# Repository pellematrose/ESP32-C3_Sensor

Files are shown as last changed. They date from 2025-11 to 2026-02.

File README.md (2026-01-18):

# ESP32-C3\_Sensor

Sensor Board to read two PT100 sensors and a Barometer. Show the measurements on a OLED Display and Broadcast over MQTT.  
With li-ion charger over USB-C.

## Hardware Components

* Two channel PT100
* Li-Ion Charging and protection circuit
* Blue user LED
* User button
* 0.9" OLED
* Li-Ion Battery connector
* Barometer

## Software Modules

* Two channel PT100 measurement with calibration.
* Access point to calibrate and configure the device and to get device information like battery voltage and temperatures.
* Measure battery voltage. (if connected)
* Display temperatures and voltage on OLED.
* Barometer
* MQTT
* Deepsleep

Device:

* Use it as stand-alone device to measure up to two temperatures and show on display. No Wifi needed.
* Use it as stand-alone device to measure up to two temperatures and check over access point.
* Use it as headless device to measure up to two temperatures and broadcast over MQTT.
* Combine the modes.
* Use it as a battery device.
* Use it without battery.
* Use it as you want. Write your own code. Use existing code. Modify existing code.
* Use. Modify. Write. Code.

# Info

All open source!

Hardware licensed under CERN-OHL-S v2 

Firmware licensed under MIT License

Makes use of mongoose.wz for HTML UI.

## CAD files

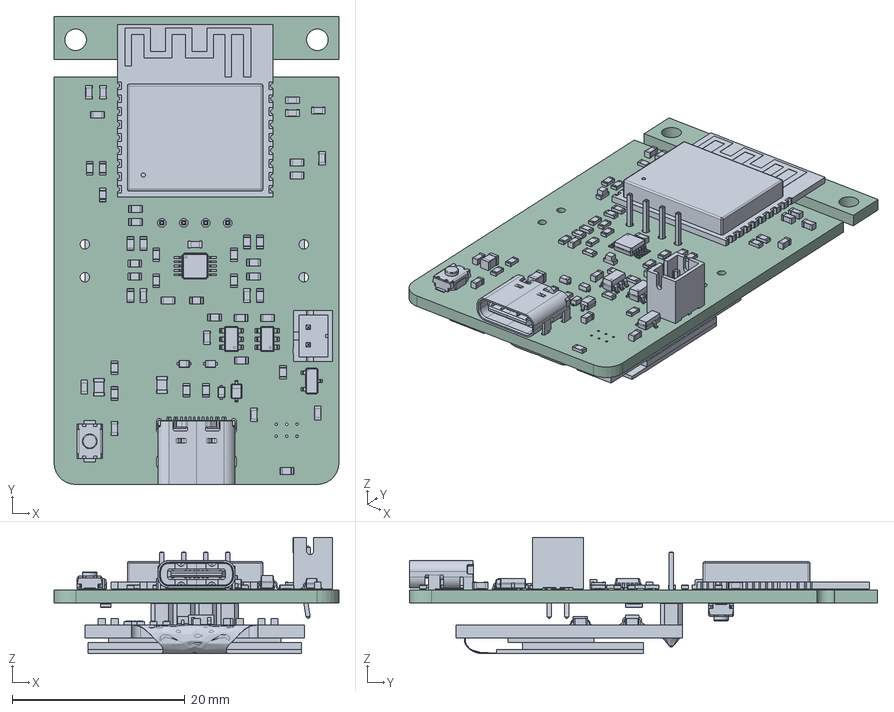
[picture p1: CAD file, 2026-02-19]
Hardware/ESP32-C3_Sensor/production_2026-02-19/step/ESP32-C3_Sensor.step
33.0 x 54.2 x 13.5 mm
R_0603_1608Metric x 32
C_0603_1608Metric x 15
SOT-23-3
JST_PH_B2B-PH-K_1x02_P2.00mm_Vertical
C_0805_2012Metric x 2
TS-1088-AR02016--3DModel-STEP-269445 x 2
ESP32-C3-WROOM-02
D_SOD-323
D_SOD-523 x 3
SOT-23-6 x 2
LED_0603_1608Metric x 2
USB_C_Receptacle_GCT_USB4105-xx-A_16P_TopMnt_Horizontal
VSSOP-10_3x3mm_P0.5mm
R_0805_2012Metric
board
screen
pin_header
soldering
smd_capacitor
smd_capacitor (1)
914_smd_resistor
472_smd_resistor x 3
t4_smd_diode
smd_capacitor (2)
smd_capacitor (3)
smd_capacitor (4)
smd_capacitor (5)
smd_capacitor (6)
472_smd_resistor (1)
SOT-23_XC6206 v3
smd_capacitor (7)
flat_cable
ESP32-C3_Sensor_PCB

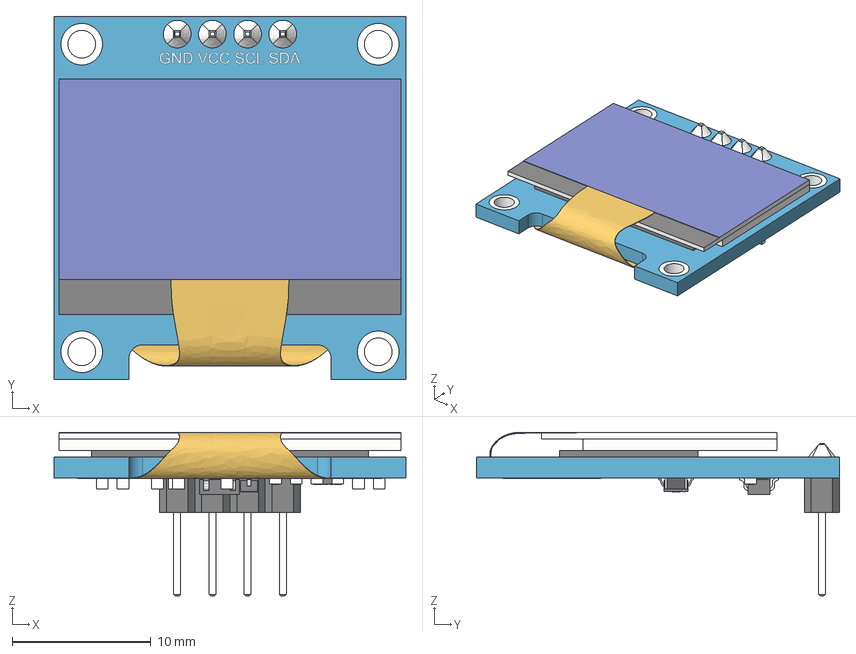
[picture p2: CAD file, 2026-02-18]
Hardware/ESP32-C3_Sensor/source_2026-02-19/3dmodels/SSD1306_OLED_Display(128x64).step
25.4 x 26.2 x 11.8 mm
board
screen
pin_header
soldering
smd_capacitor
smd_capacitor (1)
914_smd_resistor
472_smd_resistor x 3
t4_smd_diode
smd_capacitor (2)
smd_capacitor (3)
smd_capacitor (4)
smd_capacitor (5)
smd_capacitor (6)
472_smd_resistor (1)
SOT-23_XC6206 v3
smd_capacitor (7)
flat_cable

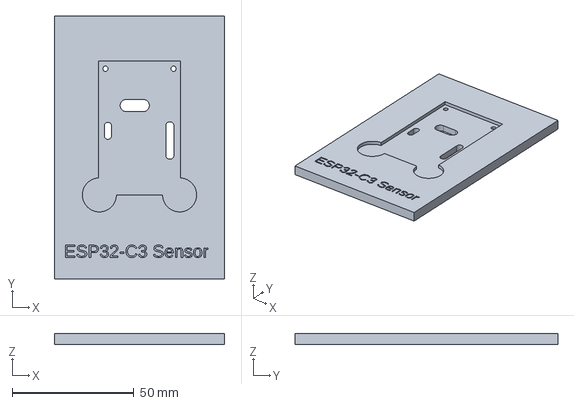
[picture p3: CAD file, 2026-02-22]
Stencil Jig/Stencil Jig.FCStd
70.0 x 108.2 x 4.60 mm

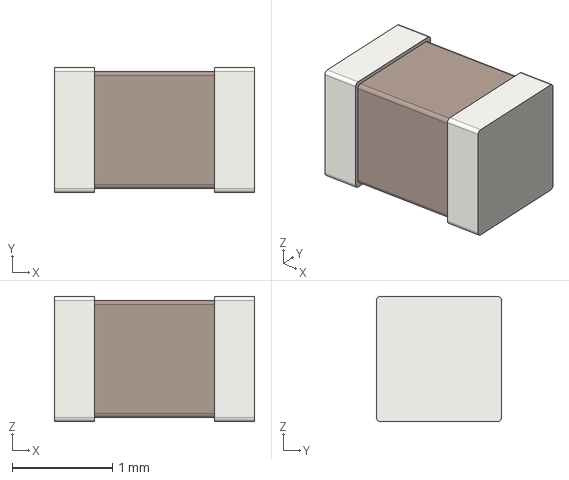
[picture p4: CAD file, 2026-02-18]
Hardware/ESP32-C3_Sensor/source_2026-02-19/3dmodels/C_0805_2012Metric.step
2.00 x 1.25 x 1.25 mm

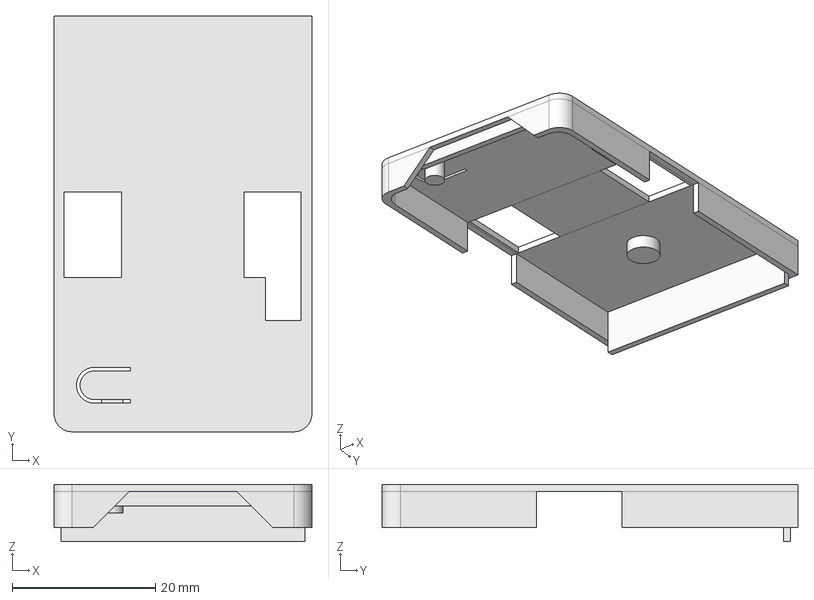
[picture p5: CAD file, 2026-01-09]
Housing/Housing-Top.step
36.0 x 58.0 x 8.00 mm

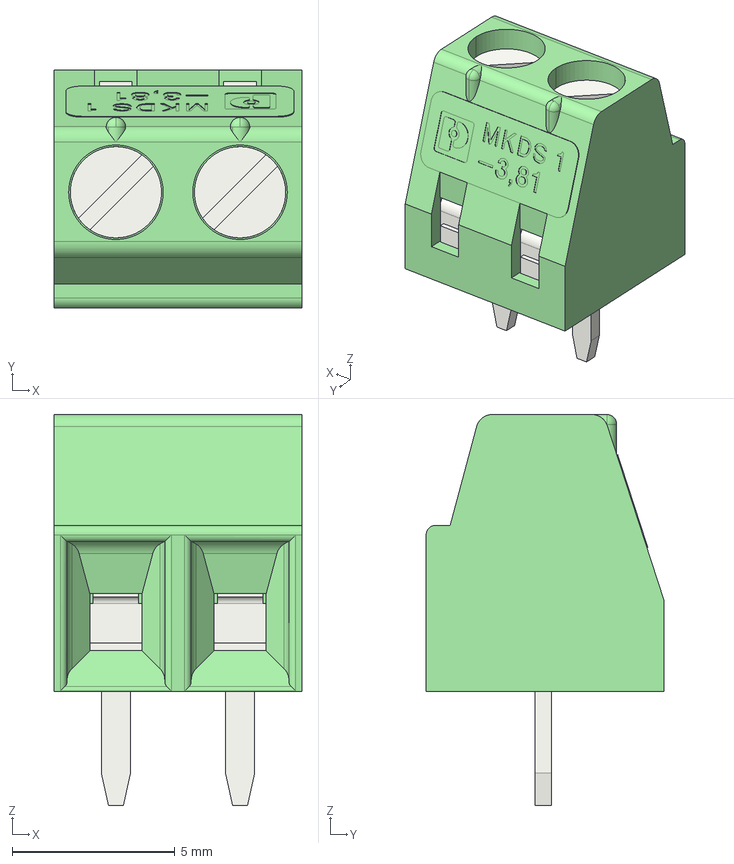
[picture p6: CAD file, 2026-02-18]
Hardware/ESP32-C3_Sensor/source_2026-02-19/3dmodels/TerminalBlock_Phoenix_MKDS-1-2-3.81_1x02_P3.81mm_Horizontal.stp
7.61 x 7.30 x 12.0 mm

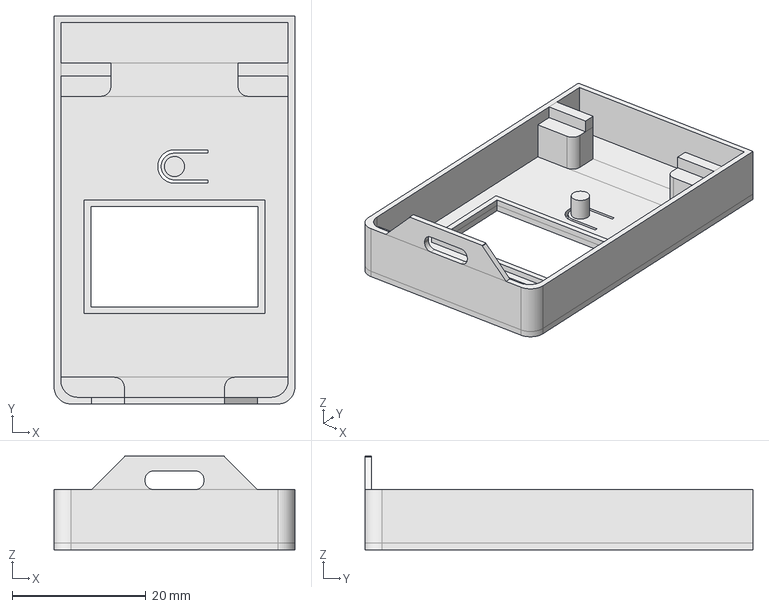
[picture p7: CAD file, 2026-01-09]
Housing/Housing-Bottom.step
36.0 x 58.0 x 14.0 mm

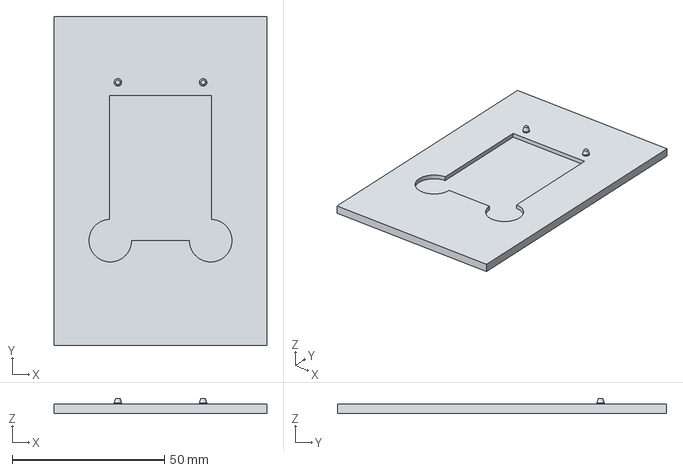
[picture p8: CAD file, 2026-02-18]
Stencil Jig/Stencil Jig-BodyPad002.step
70.0 x 108.2 x 5.00 mm

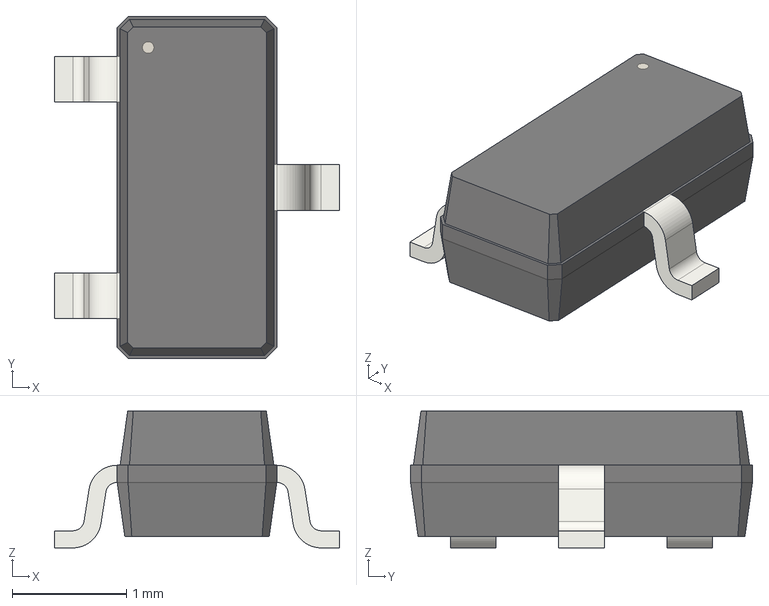
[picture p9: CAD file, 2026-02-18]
Hardware/ESP32-C3_Sensor/source_2026-02-19/3dmodels/SOT-23-3.step
2.50 x 3.00 x 1.20 mm

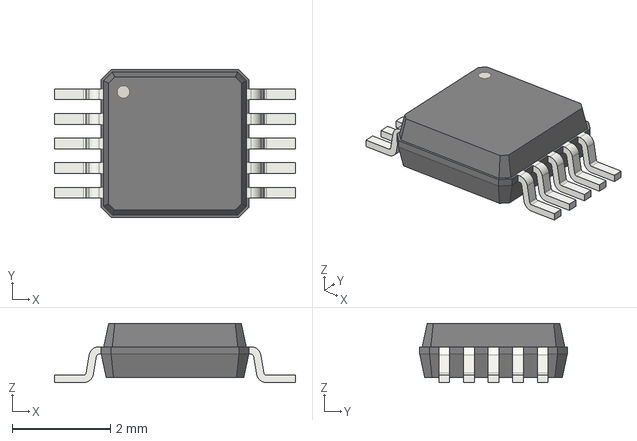
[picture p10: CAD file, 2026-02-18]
Hardware/ESP32-C3_Sensor/source_2026-02-19/3dmodels/VSSOP-10_3x3mm_P0.5mm.step
4.90 x 3.00 x 1.20 mm

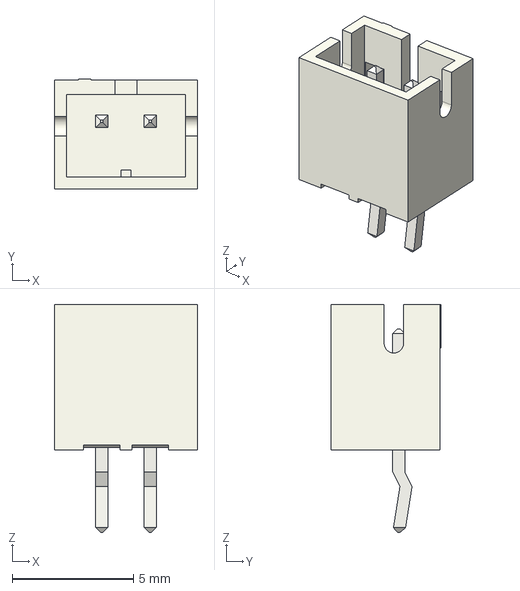
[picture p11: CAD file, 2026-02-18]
Hardware/ESP32-C3_Sensor/source_2026-02-19/3dmodels/JST_PH_B2B-PH-K_1x02_P2.00mm_Vertical.step
5.90 x 4.55 x 9.40 mm

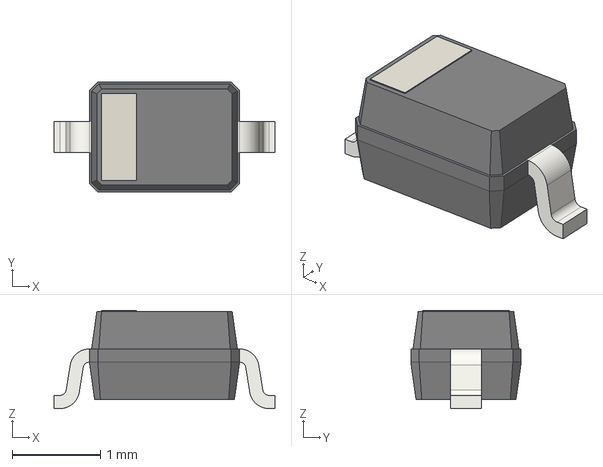
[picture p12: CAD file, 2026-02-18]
Hardware/ESP32-C3_Sensor/source_2026-02-19/3dmodels/D_SOD-323.step
2.50 x 1.25 x 1.11 mm

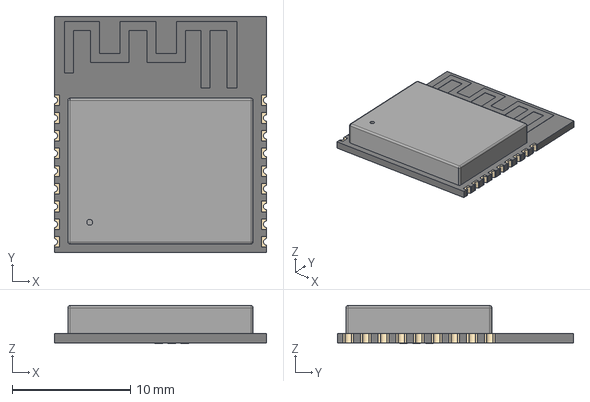
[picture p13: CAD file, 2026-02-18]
Hardware/ESP32-C3_Sensor/source_2026-02-19/3dmodels/ESP32-C3-WROOM-02.step
18.0 x 20.0 x 3.24 mm

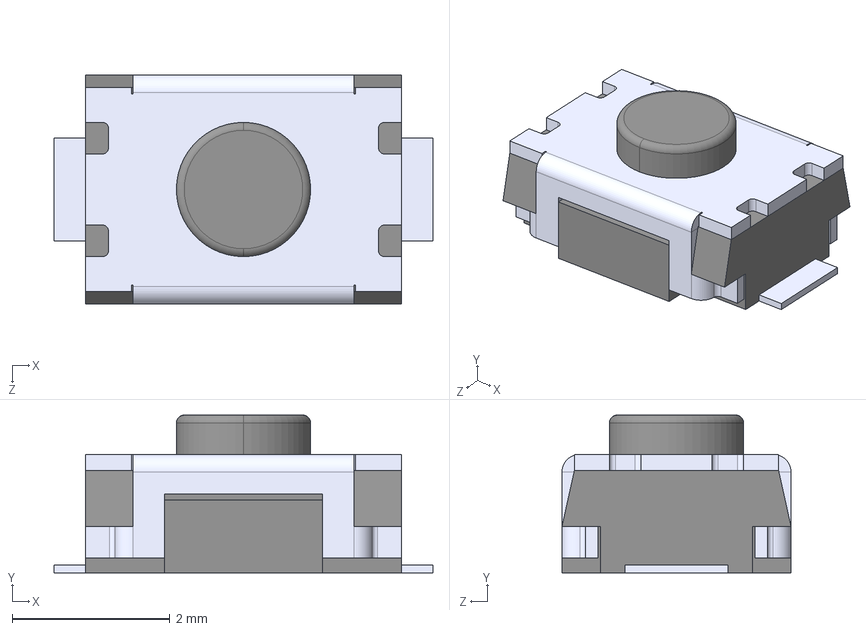
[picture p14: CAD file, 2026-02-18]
Hardware/ESP32-C3_Sensor/source_2026-02-19/3dmodels/TS-1088-AR02016--3DModel-STEP-269445.STEP
4.80 x 2.00 x 2.90 mm

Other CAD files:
Housing/Housing.FCStd
Stencil Jig/Stencil Jig-BodyPocket.step
Hardware/ESP32-C3_Sensor/source_2026-02-19/3dmodels/R_0805_2012Metric.step
Hardware/ESP32-C3_Sensor/source_2026-02-19/3dmodels/D_SOD-523.step
Hardware/ESP32-C3_Sensor/source_2026-02-19/3dmodels/BMP388.step
Hardware/ESP32-C3_Sensor/source_2026-02-19/3dmodels/C_0603_1608Metric.step
Hardware/ESP32-C3_Sensor/source_2026-02-19/3dmodels/LED_0603_1608Metric.step
Hardware/ESP32-C3_Sensor/source_2026-02-19/3dmodels/R_0603_1608Metric.step
Hardware/ESP32-C3_Sensor/source_2026-02-19/3dmodels/SOT-23-6.step
Hardware/ESP32-C3_Sensor/source_2026-02-19/3dmodels/USB_C_Receptacle_GCT_USB4105-xx-A_16P_TopMnt_Horizontal.step
Stencil Jig/20260221_Stencil Jig-BodyPocket001.step

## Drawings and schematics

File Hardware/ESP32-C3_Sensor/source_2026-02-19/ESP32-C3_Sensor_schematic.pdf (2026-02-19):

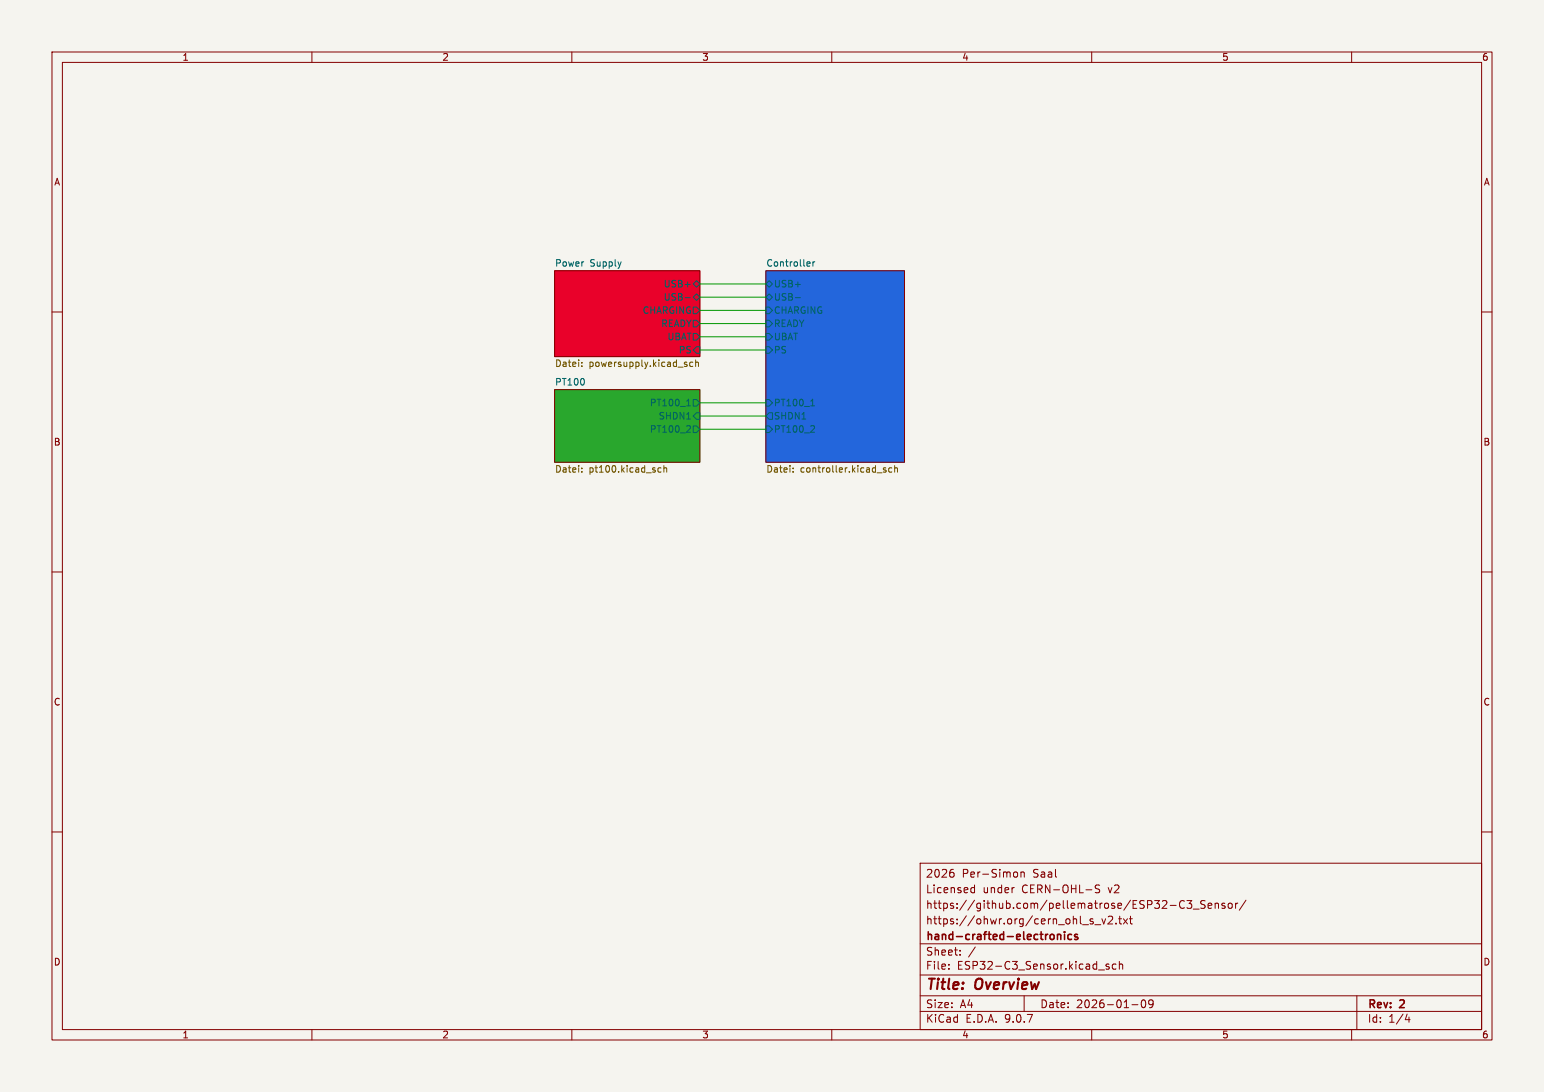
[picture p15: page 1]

UBAT PS Controller Datei: controller.kicad_sch PT100_1 SHDN1 PT100_2 PT100 Datei: pt100.kicad_sch USB+ USB- CHARGING

Power Supply Datei: powersupply.kicad_sch

USB+ USB- SHDN1 PT100_1 PT100_2 READY CHARGING

https://ohwr.org/cern_ohl_s_v2.txt
File: ESP32-C3_Sensor.kicad_sch Sheet: / hand-crafted-electronics

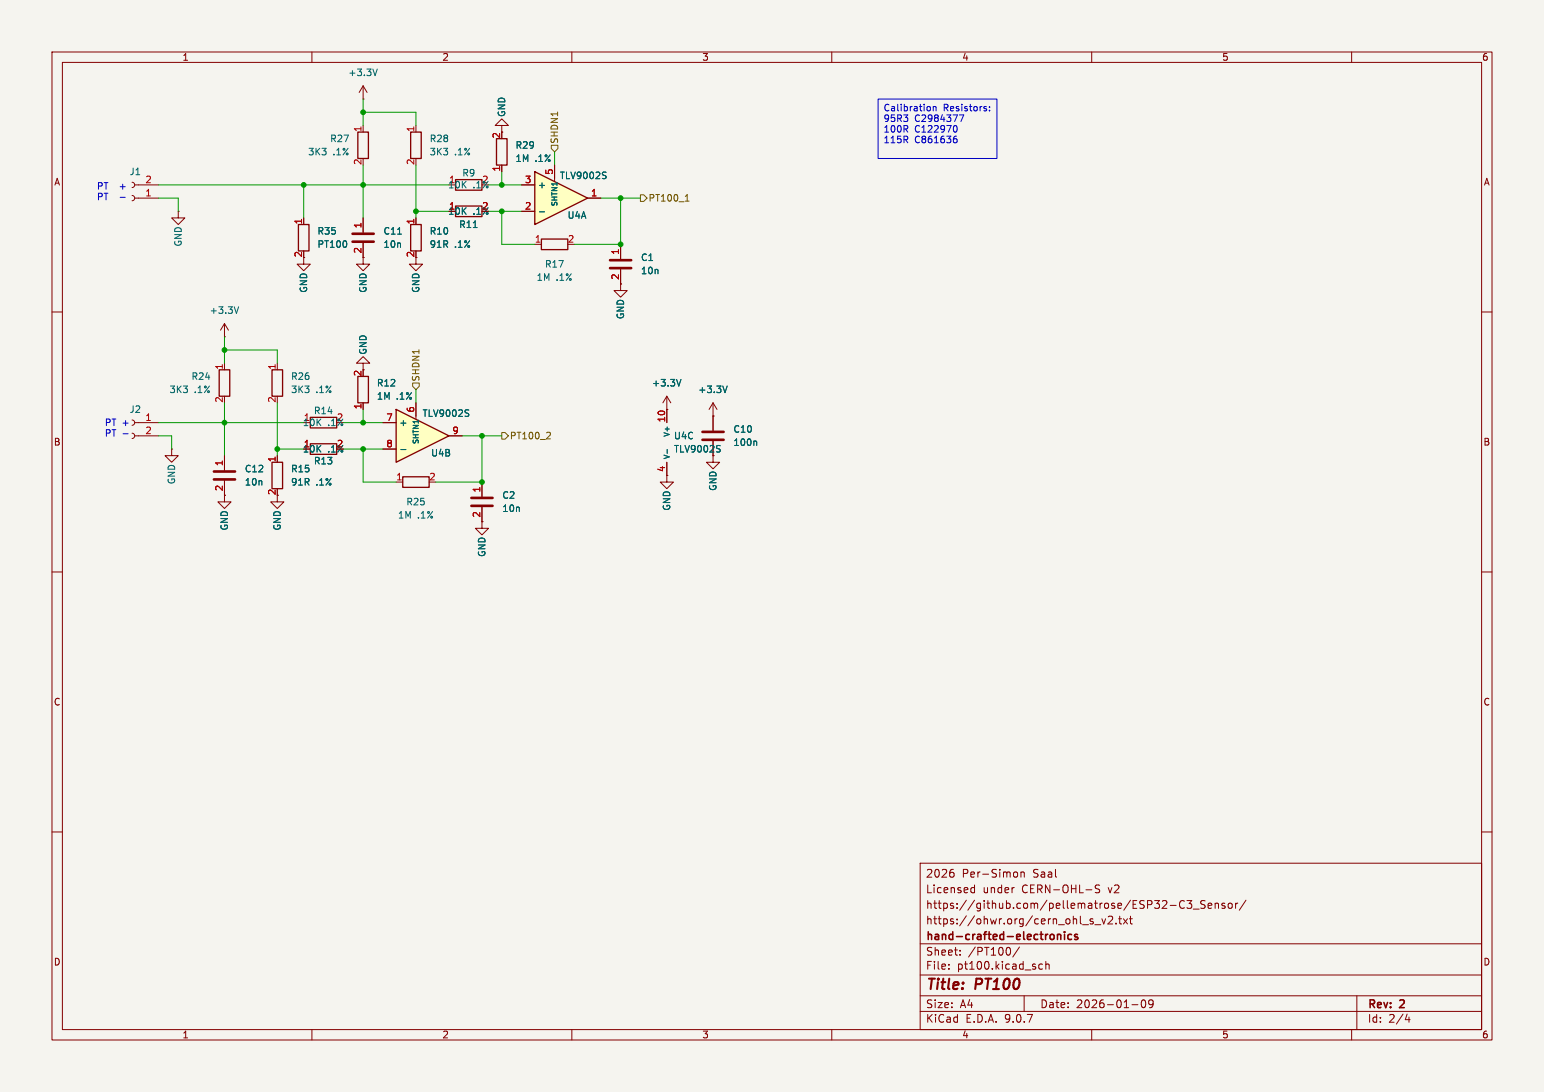
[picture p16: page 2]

https://ohwr.org/cern_ohl_s_v2.txt
File: pt100.kicad_sch Sheet: /PT100/ hand-crafted-electronics

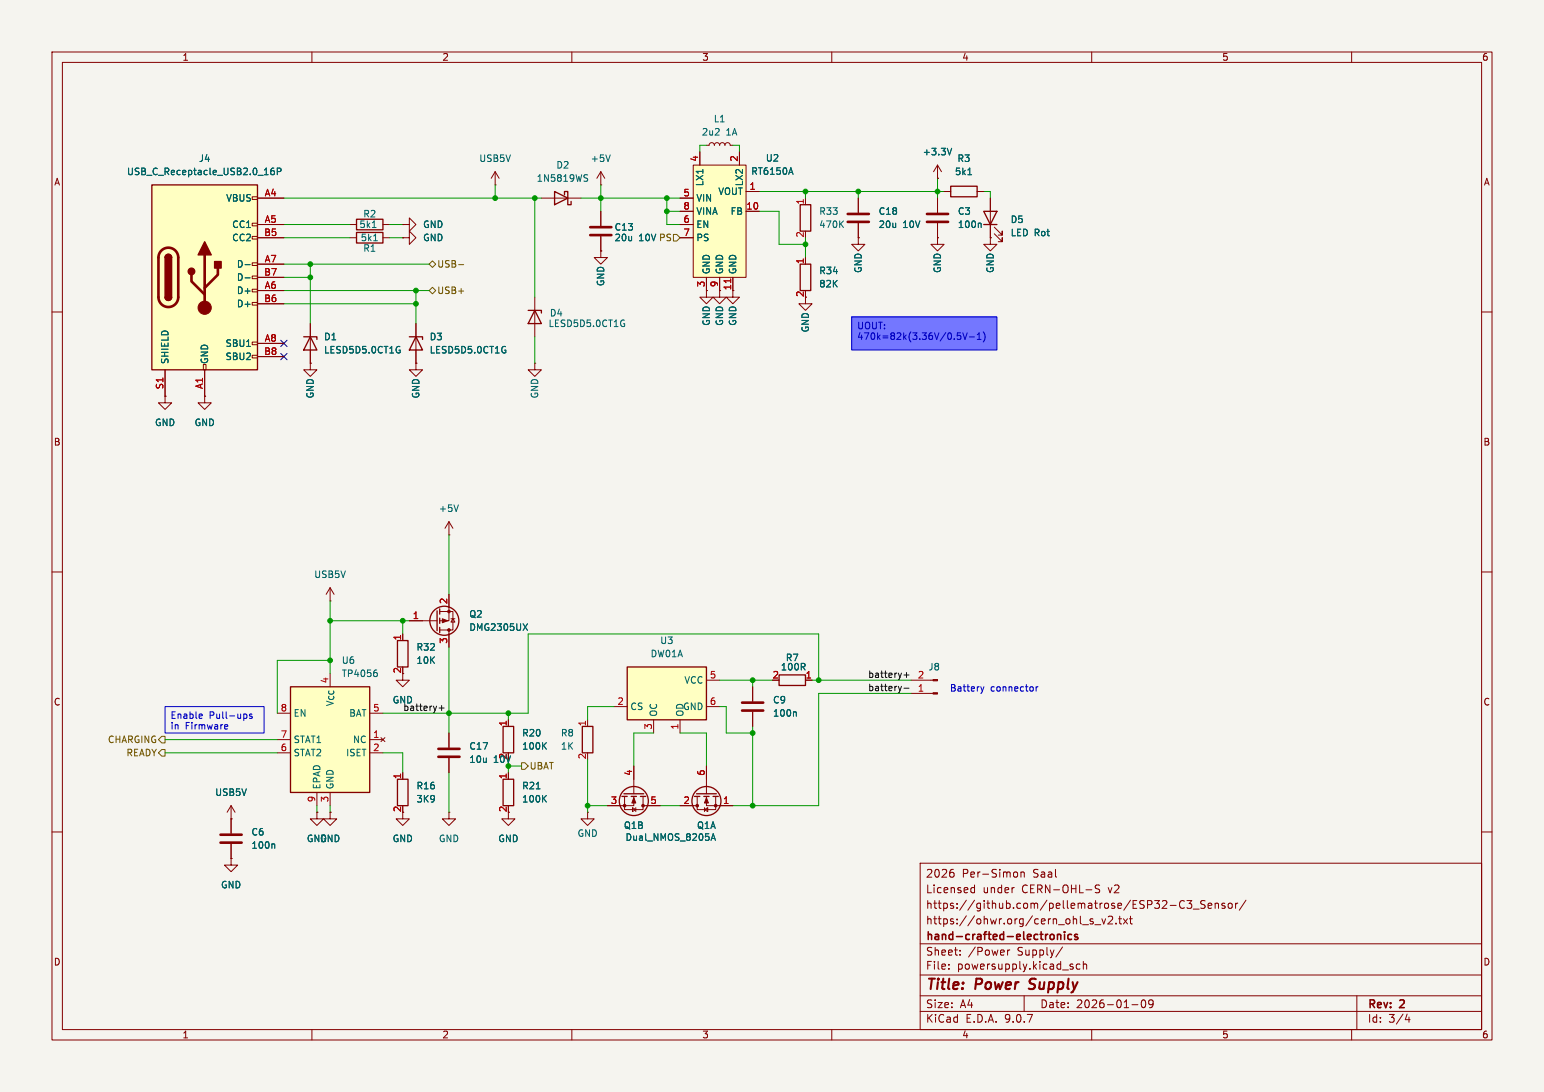
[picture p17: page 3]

VIN 5 VINA 8 EN 6 PS 7 LX1

2 VOUT 1 FB 10 U2 RT6150A

battery+ Enable Pull-ups

https://ohwr.org/cern_ohl_s_v2.txt

Id: 3/4 Title: Power Supply

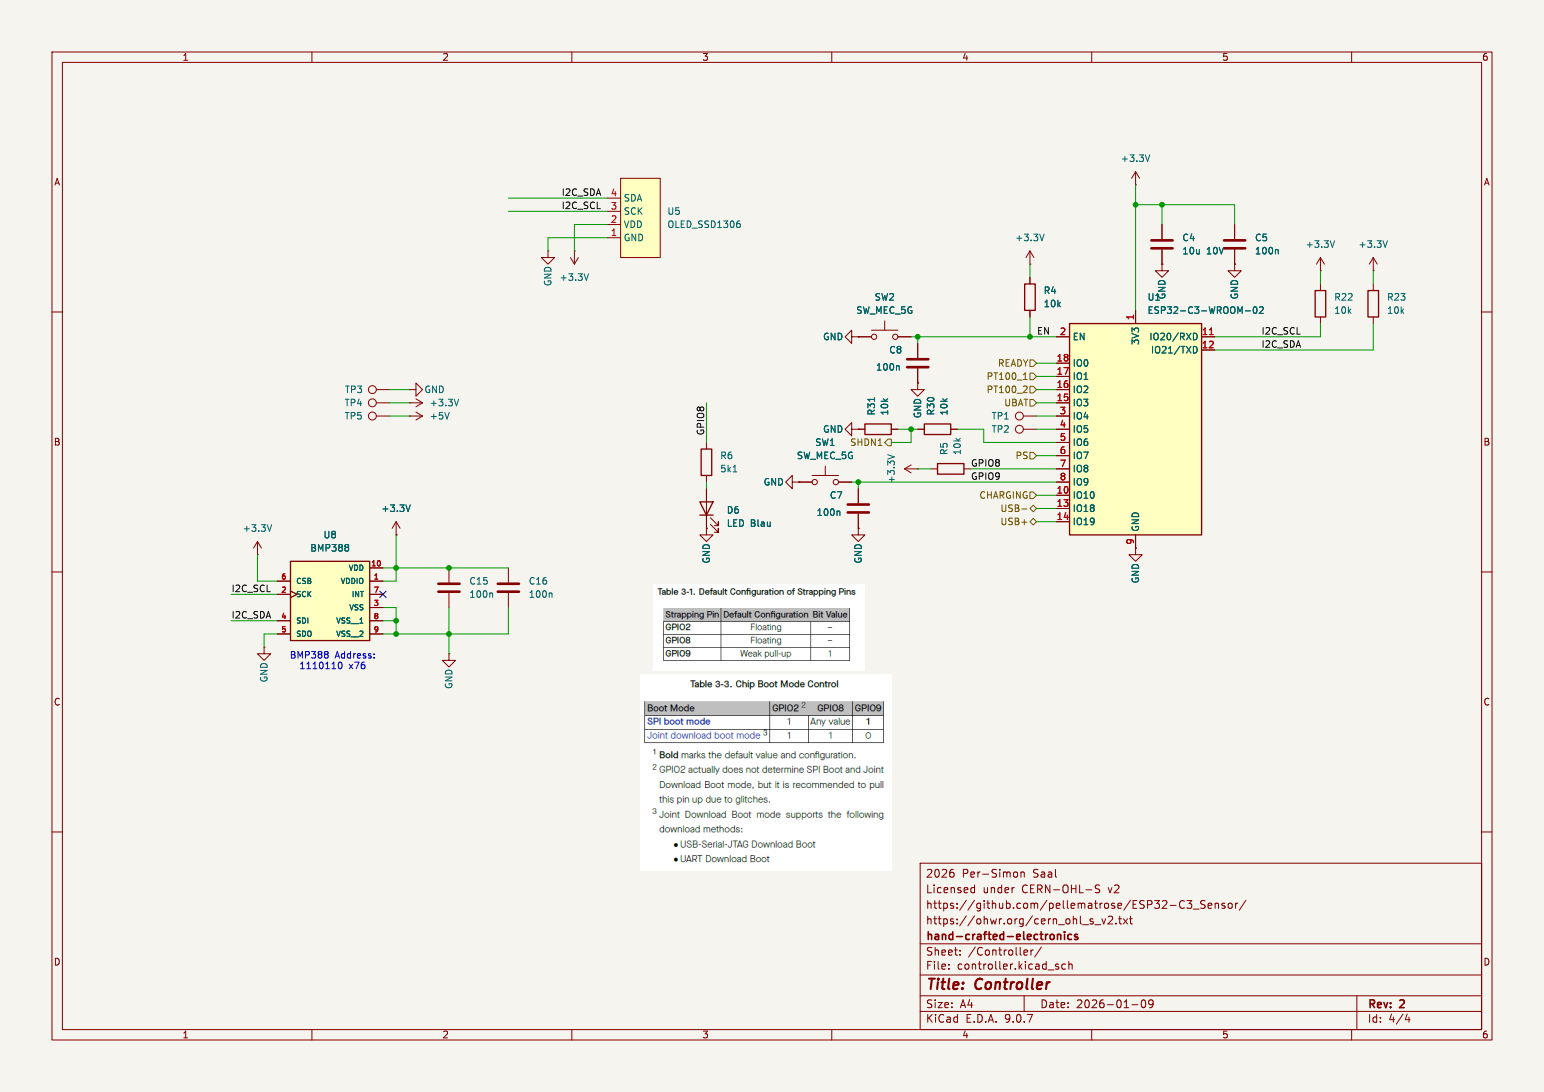
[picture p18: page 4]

https://ohwr.org/cern_ohl_s_v2.txt
Id: 4/4 Title: Controller File: controller.kicad_sch Sheet: /Controller/ hand-crafted-electronics

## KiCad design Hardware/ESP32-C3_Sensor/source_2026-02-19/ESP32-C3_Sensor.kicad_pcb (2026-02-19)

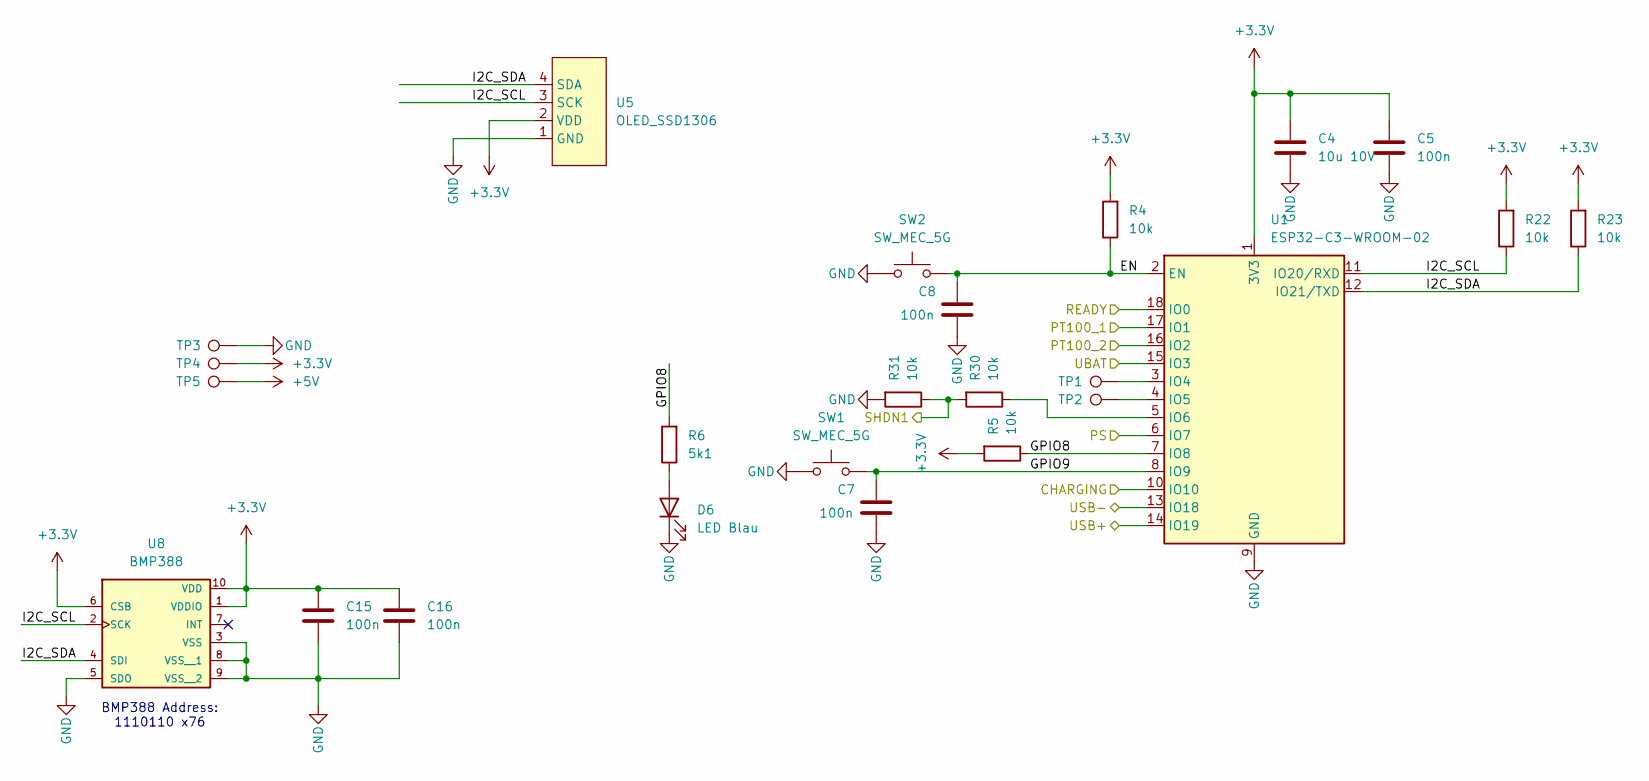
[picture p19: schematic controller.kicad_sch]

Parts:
C4: 10u 10V; C_0603_1608Metric; LCSC C2959727
C5, C7, C8, C15, C16: 100n; C_0603_1608Metric
D6: LED Blau; LED_0603_1608Metric; LCSC C965807
R4, R5, R22, R23, R30, R31: 10k; R_0603_1608Metric; LCSC C25804
R6: 5k1; R_0603_1608Metric; LCSC C431786
SW1, SW2: SW_MEC_5G; Xunpu TS-1088; LCSC C720477
TP1, TP2, TP3, TP4, TP5: TestPoint; TestPoint_Pad_D1.5mm
U1: ESP32-C3-WROOM-02; LCSC C2934560
U5: OLED_SSD1306; SSD1306_0.96_Oled
U8: BMP388; PQFN50P200X200X80-10N; PARTREV 1.1; LCSC C779278

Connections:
+3.3V: C4.1, C5.1, C15.1, C16.1, R4.2, R5.2, R22.2, R23.2, TP4.1, U1.1 (3V3), U5.2 (VDD), U8.1 (VDDIO), U8.6 (CSB), U8.10 (VDD); also elsewhere on the board
+5V: TP5.1; also elsewhere on the board
/Controller/CHARGING: U1.10 (IO10); also elsewhere on the board
/Controller/EN: C8.1, R4.1, SW2.2 (B), U1.2 (EN)
/Controller/GPIO8: R5.1, R6.2, U1.7 (IO8)
/Controller/GPIO9: C7.1, SW1.2 (B), U1.8 (IO9)
/Controller/I2C_SCL: R22.1, U1.11 (IO20/RXD), U5.3 (SCK), U8.2 (SCK)
/Controller/I2C_SDA: R23.1, U1.12 (IO21/TXD), U5.4 (SDA), U8.4 (SDI)
/Controller/PS: U1.6 (IO7); also elsewhere on the board
/Controller/PT100_1: U1.17 (IO1); also elsewhere on the board
/Controller/PT100_2: U1.16 (IO2); also elsewhere on the board
/Controller/READY: U1.18 (IO0); also elsewhere on the board
/Controller/SHDN1: R30.2, R31.1; also elsewhere on the board
/Controller/UBAT: U1.15 (IO3); also elsewhere on the board
/Controller/USB+: U1.14 (IO19); also elsewhere on the board
/Controller/USB-: U1.13 (IO18); also elsewhere on the board
GND: C4.2, C5.2, C7.2, C8.2, C15.2, C16.2, D6.1 (K), R31.2, SW1.1 (A), SW2.1 (A), TP3.1, U1.9 (GND), U1.19 (GND), U5.1 (GND), U8.3 (VSS), U8.5 (SDO), U8.8 (VSS__1), U8.9 (VSS__2); also elsewhere on the board
unnamed: D6.2 (A), R6.1
unnamed: TP1.1, U1.3 (IO4)
unnamed: TP2.1, U1.4 (IO5)
unnamed: R30.1, U1.5 (IO6)

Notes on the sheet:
BMP388 Address: 1110110 x76

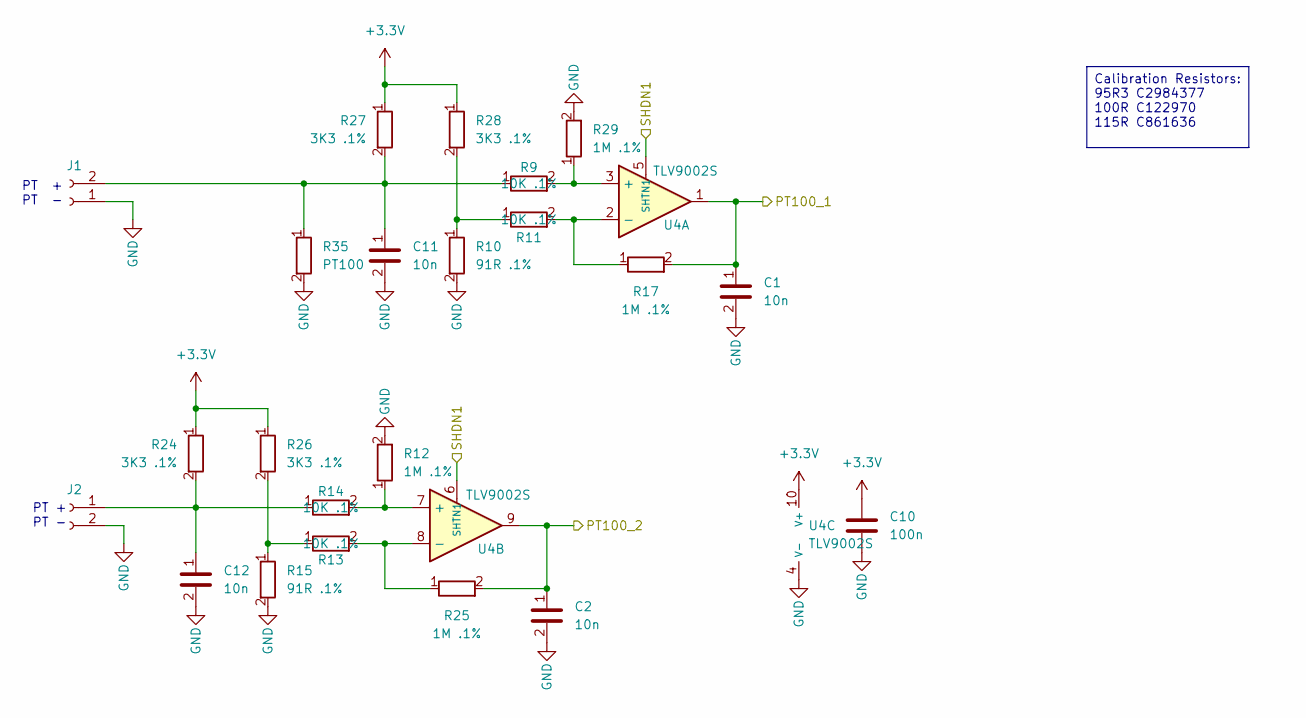
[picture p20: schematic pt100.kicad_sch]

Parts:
C1, C2, C11, C12: 10n; C_0603_1608Metric
C10: 100n; C_0603_1608Metric
J1, J2: Conn_01x02_Socket; TerminalBlock_Phoenix_MKDS-1-2-3.81_1x02_P3.81mm_Horizontal
R9, R11, R13, R14: 10K .1%; R_0603_1608Metric; LCSC C95204
R10, R15: 91R .1%; R_0603_1608Metric; LCSC C862316
R12, R17, R25, R29: 1M .1%; R_0603_1608Metric; LCSC C2989464
R24, R26, R27, R28: 3K3 .1%; R_0603_1608Metric; LCSC C309653
R35: PT100; R_0805_2012Metric
U4: TLV9002S; VSSOP-10_3x3mm_P0.5mm; LCSC C2058239

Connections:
+3.3V: C10.1, R24.1, R26.1, R27.1, R28.1, U4.10 (V+); also elsewhere on the board
/Controller/PT100_1: C1.1, R17.2, U4.1; also elsewhere on the board
/Controller/PT100_2: C2.1, R25.2, U4.9; also elsewhere on the board
/Controller/SHDN1: U4.5 (SHTN1), U4.6 (SHTN1); also elsewhere on the board
GND: C1.2, C2.2, C10.2, C11.2, C12.2, J1.1, J2.2, R10.2, R12.2, R15.2, R29.2, R35.2, U4.4 (V-); also elsewhere on the board
unnamed: C11.1, J1.2, R9.1, R27.2, R35.1
unnamed: C12.1, J2.1, R14.1, R24.2
unnamed: R10.1, R11.1, R28.2
unnamed: R13.1, R15.1, R26.2
unnamed: R9.2, R29.1, U4.3 (+)
unnamed: R11.2, R17.1, U4.2 (-)
unnamed: R12.1, R14.2, U4.7 (+)
unnamed: R13.2, R25.1, U4.8 (-)

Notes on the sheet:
PT + PT -
PT + PT -
Calibration Resistors: 95R3 C2984377 100R C122970 115R C861636

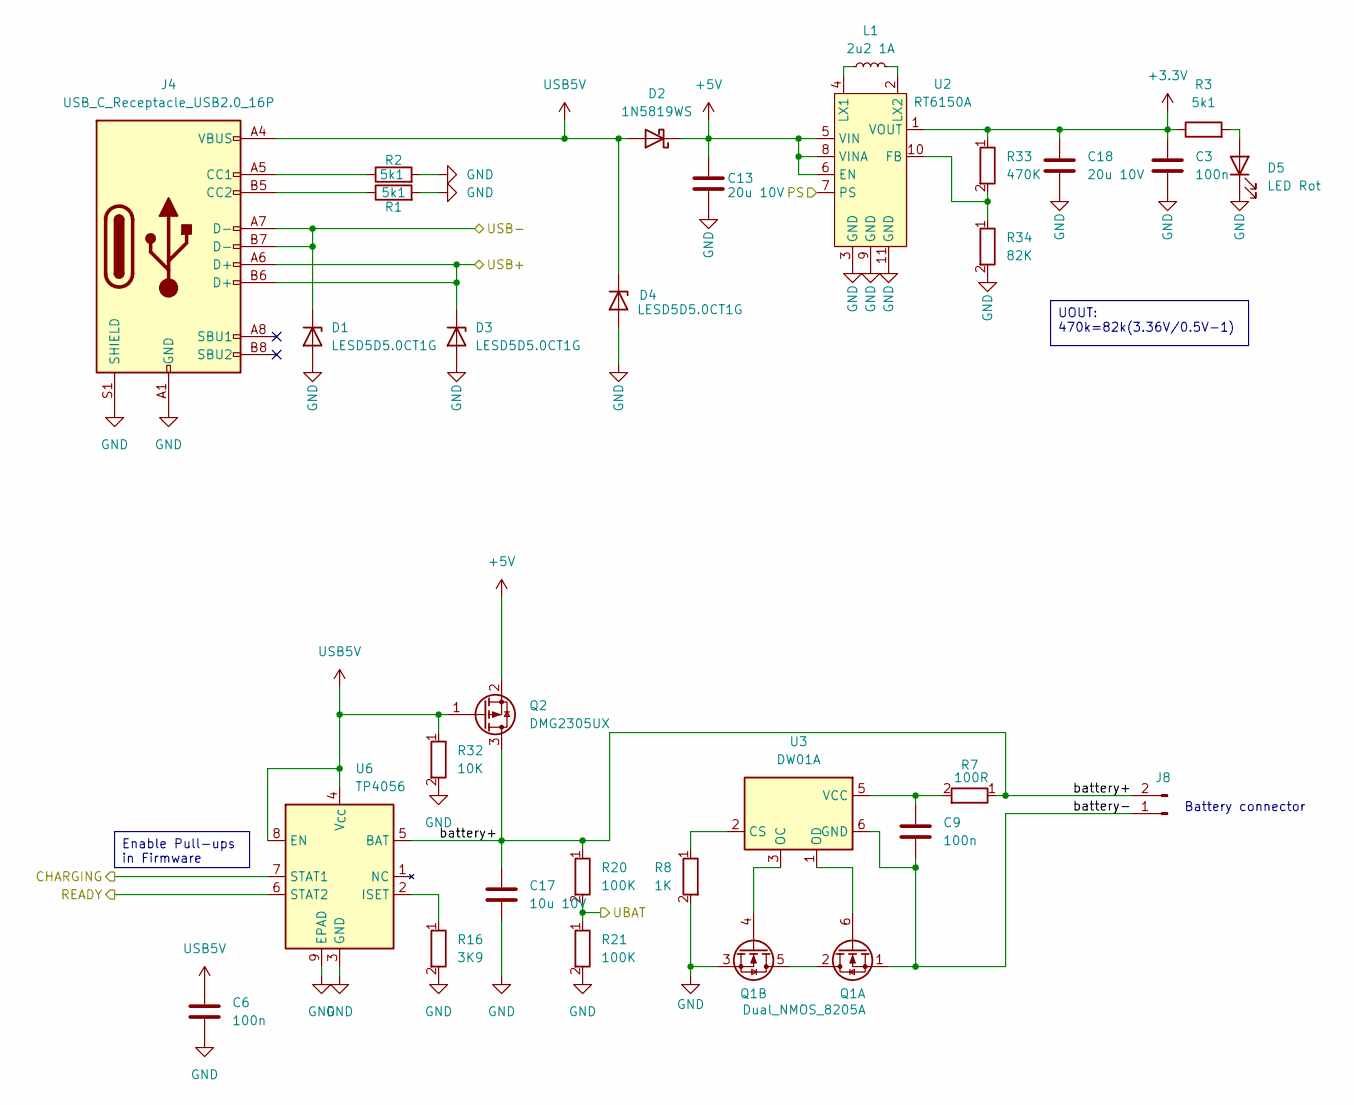
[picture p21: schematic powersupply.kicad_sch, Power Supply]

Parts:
C3, C6, C9: 100n; C_0603_1608Metric
C13, C18: 20u 10V; C_0805_2012Metric
C17: 10u 10V; C_0603_1608Metric; LCSC C2959727
D1, D3, D4: LESD5D5.0CT1G; D_SOD-523; LCSC C383211
D2: 1N5819WS; D_SOD-323; LCSC C2939001
D5: LED Rot; LED_0603_1608Metric; LCSC C965799
J4: USB_C_Receptacle_USB2.0_16P; USB_C_Receptacle_GCT_USB4105-xx-A_16P_TopMnt_Horizontal; LCSC C2988369
J8: Conn_01x02_Pin; JST_PH_B2B-PH-K_1x02_P2.00mm_Vertical
L1: 2u2 1A; Inductor_1210; LCSC C39846664
Q1: Dual_NMOS_8205A; SOT-23-6; LCSC C5370944
Q2: DMG2305UX; SOT-23-3; LCSC C150470
R1, R2, R3: 5k1; R_0603_1608Metric; LCSC C431786
R7: 100R; R_0603_1608Metric; LCSC C22775
R8: 1K; R_0603_1608Metric; LCSC C21190
R16: 3K9; R_0603_1608Metric; LCSC C23018
R20, R21: 100K; R_0603_1608Metric; LCSC C25803
R32: 10K; R_0603_1608Metric; LCSC C25804
R33: 470K; R_0603_1608Metric; LCSC C23178
R34: 82K; R_0603_1608Metric; LCSC C23254
U2: RT6150A; WDFN-10-1EP_3x3mm_P0.5mm_EP1.8x2.5mm; LCSC C147971
U3: DW01A; SOT-23-6; LCSC C2927799
U6: TP4056; SOIC-8-1EP_3.9x4.9mm_P1.27mm_EP2.41x3.3mm_ThermalVias; LCSC C725790

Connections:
+3.3V: C3.1, C18.1, R3.1, R33.1, U2.1 (VOUT); also elsewhere on the board
+5V: C13.1, D2.1 (K), Q2.2 (S), U2.5 (VIN), U2.6 (EN), U2.8 (VINA); also elsewhere on the board
/Controller/CHARGING: U6.7 (STAT1); also elsewhere on the board
/Controller/PS: U2.7 (PS); also elsewhere on the board
/Controller/READY: U6.6 (STAT2); also elsewhere on the board
/Controller/UBAT: R20.2, R21.1; also elsewhere on the board
/Controller/USB+: D3.1 (K), J4.A6 (D+), J4.B6 (D+); also elsewhere on the board
/Controller/USB-: D1.1 (K), J4.A7 (D-), J4.B7 (D-); also elsewhere on the board
/Power Supply/battery+: C17.1, J8.2, Q2.3 (D), R7.1, R20.1, U6.5 (BAT)
/Power Supply/battery-: C9.2, J8.1, Q1.1 (S), U3.6 (GND)
GND: C3.2, C6.2, C13.2, C17.2, C18.2, D1.2 (A), D3.2 (A), D4.2 (A), D5.1 (K), J4.A1 (GND), J4.A12 (GND), J4.B1 (GND), J4.B12 (GND), J4.S1 (SHIELD), Q1.3 (S), R1.2, R2.2, R8.2, R16.2, R21.2, R32.2, R34.2, U2.3 (GND), U2.9 (GND), U2.11 (GND), U6.3 (GND), U6.9 (EPAD); also elsewhere on the board
unnamed: D5.2 (A), R3.2
unnamed: J4.A5 (CC1), R2.1
unnamed: J4.B5 (CC2), R1.1
unnamed: Q1.2 (D), Q1.5 (D)
unnamed: Q1.6 (G), U3.1 (OD)
unnamed: Q1.4 (G), U3.3 (OC)
unnamed: R33.2, R34.1, U2.10 (FB)
unnamed: L1.1, U2.4 (LX1)
unnamed: L1.2, U2.2 (LX2)
unnamed: R8.1, U3.2 (CS)
unnamed: C9.1, R7.2, U3.5 (VCC)
unnamed: R16.1, U6.2 (ISET)
USB5V: C6.1, D2.2 (A), D4.1 (K), J4.A4 (VBUS), J4.A9 (VBUS), J4.B4 (VBUS), J4.B9 (VBUS), Q2.1 (G), R32.1, U6.4 (V_{CC}), U6.8 (EN)

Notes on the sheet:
Battery connector
UOUT: 470k=82k(3.36V/0.5V-1)
Enable Pull-ups in Firmware

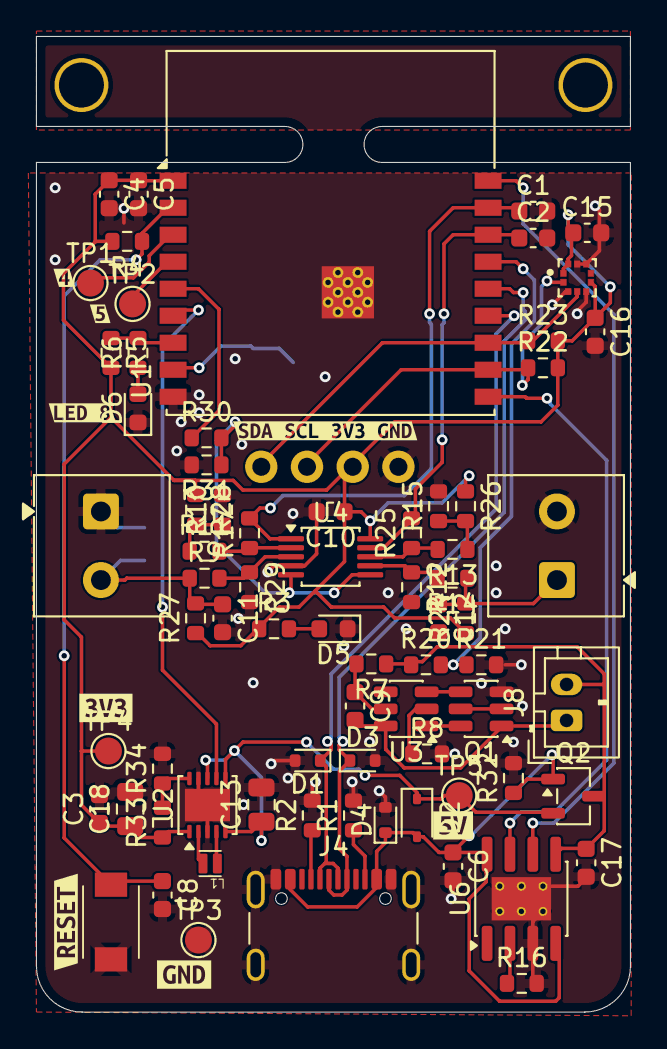
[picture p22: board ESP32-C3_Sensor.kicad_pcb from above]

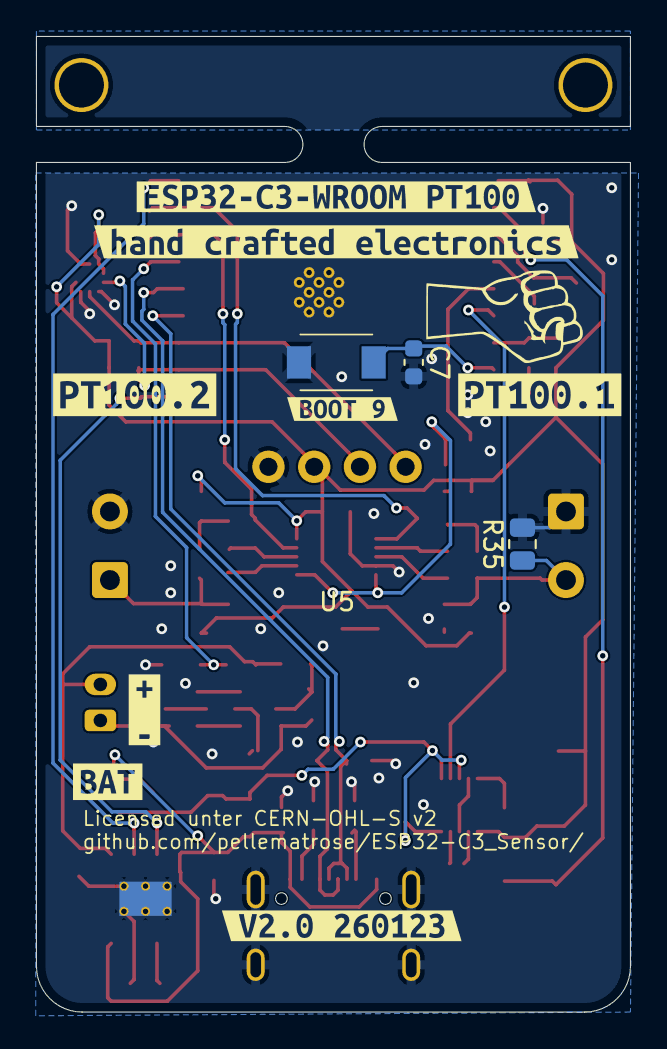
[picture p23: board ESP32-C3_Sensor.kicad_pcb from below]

Board: 2 copper layers, 33.0 x 54.2 mm, 95 parts (12 on the bottom side), 44 nets.

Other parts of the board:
H*: Stencil hole
H*#2: Stencil hole
kibuzzard-68E97F46: G***; kibuzzard-68E97F46
kibuzzard-68E980D7: G***; kibuzzard-68E980D7
kibuzzard-68E983D3: G***; kibuzzard-68E983D3
kibuzzard-68E983DB: G***; kibuzzard-68E983DB
kibuzzard-68E985AE: G***; kibuzzard-68E985AE
kibuzzard-68E986EB: G***; kibuzzard-68E986EB
kibuzzard-68E9848D: G***; kibuzzard-68E9848D
kibuzzard-68E9870E: G***; kibuzzard-68E9870E
kibuzzard-68E98065: G***; kibuzzard-68E98065
kibuzzard-68EE716B: G***; kibuzzard-68EE716B
kibuzzard-68EE7166: G***; kibuzzard-68EE7166
kibuzzard-679A5C2F: G***; kibuzzard-679A5C2F
kibuzzard-679A571E: G***; kibuzzard-679A571E
kibuzzard-696E7314: G***; kibuzzard-696E7314
kibuzzard-69307756: G***; kibuzzard-69307756
kibuzzard-69738792: G***; kibuzzard-69738792

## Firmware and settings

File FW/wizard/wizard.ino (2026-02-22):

/*
 * SPDX-License-Identifier: MIT
 *
 * Copyright (c) 2026 Per-Simon Saal
 */
 
#include "src/mongoose_glue.h"
#include "my_globals.h"

//#include <ESPAsyncWebServer.h>
//#include <AsyncTCP.h>
#include <EEPROM.h>
#include <stdbool.h>
#include "my_functions.h"
#include "setup_pins.h"
#include <driver/adc.h>
#include <esp_adc_cal.h>
#include "temp_func.h"
#include "wifi_manager.h"
#include <U8g2lib.h>
#include "oled_gui.h"
#include <Wire.h>
#include <Adafruit_Sensor.h>
#include "Adafruit_BMP3XX.h"
#include "WiFi.h"
#include "io_func.h"
#include "storage.h"

#define ADC_CHANNEL1 ADC1_CHANNEL_1  // GPIO1
#define ADC_CHANNEL2 ADC1_CHANNEL_2  // GPIO2
#define ADC_CHANNEL3 ADC1_CHANNEL_3  // GPIO3
#define DEFAULT_VREF 1100           // in mV, typischer Wert

// ADC
esp_adc_cal_characteristics_t adc_chars;

// I2C
TwoWire myWire = TwoWire(0);

// OLED
U8G2_SSD1306_128X64_NONAME_F_HW_I2C u8g2(U8G2_R0, /* reset=*/ U8X8_PIN_NONE, /* clock=*/ 20, /* data=*/ 21);   // ESP32 Thing, HW I2C with pin remapping

// BMP388
Adafruit_BMP3XX bmp;

// variables
float temp1 = 0;
float temp2 = 0;
float pressure = 0;
uint32_t vol = 0;
bool chrg = 0;
bool rdy = 0;
float temp1_15min[15];
float temp2_15min[15];
float pressure_15min[15];
float temp1_15minavg = 0;
float temp2_15minavg = 0;
float pressure_15minavg = 0;
uint8_t count = 0;
uint8_t oled_state = 0; // 2: off, 0: temps, 1: bat

// - timing
uint32_t now = 0;
uint32_t last1min = 0;
uint32_t last15min = 0;
uint32_t delta1min = 60000;  
uint32_t delta15min = 900000;
uint32_t oledoff = 5000;
uint32_t olednow = 0;

void setup() {
  Serial.begin(115200);
  delay(100);

  // pin definitions
  setup_pins();
  
  // Legacy ADC konfigurieren
  adc1_config_width(ADC_WIDTH_BIT_12);
  adc1_config_channel_atten(ADC_CHANNEL1, ADC_ATTEN_DB_11); // PT100 1: 0 dB = 0,85V, 2.5dB = 1,3V, 6dB = 2V, 11dB = 3,3V
  adc1_config_channel_atten(ADC_CHANNEL2, ADC_ATTEN_DB_11); // PT100 2
  adc1_config_channel_atten(ADC_CHANNEL3, ADC_ATTEN_DB_11); // Battery voltage
  // Kalibrierung initialisieren
  esp_adc_cal_characterize(ADC_UNIT_1, ADC_ATTEN_DB_11, ADC_WIDTH_BIT_12, DEFAULT_VREF, &adc_chars);

  EEPROM.begin(512); // oder eine andere Größe, je nach Bedarf
  check_magic();
  load(CAL_ADDRESS, (void *)voltages_cal, sizeof(voltages_cal));
  load(ZERO_ADDRESS, (void *)zero_cal, sizeof(zero_cal));

  myWire.begin(21, 20, 400000); // SDA, SCL, Freq
  if(!bmp.begin_I2C(0x76, &myWire)){
    Serial.println("BMP Error.");
  }
  // OLED
  u8g2.begin();
  u8g2.enableUTF8Print();

  // Set up oversampling and filter initialization
  bmp.setTemperatureOversampling(BMP3_OVERSAMPLING_8X);
  bmp.setPressureOversampling(BMP3_OVERSAMPLING_4X);
  bmp.setIIRFilterCoeff(BMP3_IIR_FILTER_COEFF_3);
  bmp.setOutputDataRate(BMP3_ODR_50_HZ);

  // Set logging function to serial print
  mg_log_set_fn([](char ch, void *) { Serial.print(ch); }, NULL);
  mg_log_set(MG_LL_DEBUG);

  connect_wifi();
  mqtt_setup();
  
  // fill arrays with real values
  // TODO: put in own function
  if (! bmp.performReading()) {
  Serial.println("Failed to perform reading :(");
  return;
  }
  for(int i=0; i<15; i++){
    temp1_15min[i] = get_temperature(1) - zero_cal[0];
    temp2_15min[i] = get_temperature(2) - zero_cal[1]+1.7; //TODO: Channel two somehow shows a false value on my hardware (remove 1.7!)
    pressure_15min[i] = bmp.pressure / 100;
  }
  temp1_15minavg = moving_average(temp1_15min, 15);
  temp2_15minavg = moving_average(temp2_15min, 15);
  pressure_15minavg = moving_average(pressure_15min, 15);
  vol = get_voltage(3) * 2; // 100k : 100k voltage divider
  chrg = get_charge_Pin();
  rdy = get_ready_Pin();
  Serial.printf("t1: %.1f, t2: %.1f, p: %.2f, vol: %.3f", temp1_15minavg, temp2_15minavg, pressure_15minavg, vol);
  oled_data(temp1_15minavg, temp2_15minavg, pressure_15minavg);
  // fill array function end

  //esp_sleep_enable_timer_wakeup(900000000);

  mongoose_init();
  mongoose_set_http_handlers("battery", my_get_battery, my_set_battery);
  mongoose_set_http_handlers("temperature", my_get_temperature, my_set_temperature);
  mongoose_set_http_handlers("wifi", my_get_wifi, my_set_wifi);
  mongoose_set_http_handlers("debug", my_get_debug, my_set_debug);
  mongoose_set_http_handlers("mqtt", my_get_mqtt, my_set_mqtt);
  mongoose_set_http_handlers("calibration", my_get_calibration, my_set_calibration);
  mongoose_set_http_handlers("btnhigh", my_check_btnhigh, my_start_btnhigh);
  mongoose_set_http_handlers("btnlow", my_check_btnlow, my_start_btnlow);
  mongoose_set_http_handlers("btnhigh2", my_check_btnhigh2, my_start_btnhigh2);
  mongoose_set_http_handlers("btnlow2", my_check_btnlow2, my_start_btnlow2);
  mongoose_set_http_handlers("resetcal1", my_check_resetcal1, my_start_resetcal1);
  mongoose_set_http_handlers("resetcal2", my_check_resetcal2, my_start_resetcal2);
  mongoose_set_http_handlers("tempoffset1", my_check_tempoffset1, my_start_tempoffset1);
  mongoose_set_http_handlers("tempoffset2", my_check_tempoffset2, my_start_tempoffset2);
  mongoose_set_http_handlers("reboot", my_check_reboot, my_start_reboot);

}

void loop() {
  mongoose_poll();

  now = millis();
  //Serial.println("läuft");
  
  // mqtt
  if(apmode == 1 && mqttdata.en == true){
    mqtt_loop();
  }
  
  
  // time loop one
  if(now - last1min > delta1min){
    last1min = now;

    temp1 = get_temperature(1) - zero_cal[0];
    temp2 = get_temperature(2) - zero_cal[1]+1.7; //TODO: Channel two somehow shows a false value on my hardware (remove 1.7!)
    
    if (! bmp.performReading()) {
      Serial.println("Failed to perform reading :(");
      return;
    }
    pressure = bmp.pressure / 100;
    
    if(count == 15) count = 0; // reset counter when at end of array
    temp1_15min[count] = temp1;
    temp2_15min[count] = temp2;
    pressure_15min[count] = pressure;
    count++;
    temp1_15minavg = moving_average(temp1_15min, 15);
    temp2_15minavg = moving_average(temp2_15min, 15);
    pressure_15minavg = moving_average(pressure_15min, 15);
    //TODO: read battery voltage and charge status
    vol = get_voltage(3) * 2; // 100k : 100k voltage divider
    chrg = get_charge_Pin();
    rdy = get_ready_Pin();

    Serial.printf("%.1f°C, %.1f°C, %.1fhPa, %dmV\n", temp1_15minavg, temp2_15minavg, pressure_15minavg, vol);
    
    
  }

  // time loop two
  if(now - last15min > delta15min){
    last15min = now;
      // mqtt
    if(apmode == 1 && mqttdata.en == true){
      mqtt_publish();
    }
  }
  
  if(millis() - olednow > oledoff){
    olednow = millis();
    oled_off();
    oled_state = 0; // oled off
  }
  // cycle through screens. TODO: debounce button!
  if(get_buttonboot_Pin()==0){
    switch (oled_state) {
      case 0: oled_data(temp1_15minavg, temp2_15minavg, pressure_15minavg);
              oled_state++;
              break; // increment
      case 1: oled_auxdata(vol);
              oled_state++; 
              break;
      case 2: oled_off(); 
              oled_state = 0;
              break;
      default: oled_off(); 
              break;
    }
    delay(200);
  }
}

extern "C" int lwip_hook_ip6_input(struct pbuf *p, struct netif *inp) __attribute__((weak));
extern "C" int lwip_hook_ip6_input(struct pbuf *p, struct netif *inp) {
  if (ip6_addr_isany_val(inp->ip6_addr[0].u_addr.ip6)) {
    pbuf_free(p);
    return 1;
  }
  return 0;
}

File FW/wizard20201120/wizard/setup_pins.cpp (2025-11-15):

#include "setup_pins.h"
#include <Arduino.h>
#include "my_globals.h"

// constants
const int readyPin = 0; // lo when finished with charging
//const int temp1Pin = 1; // ADC1_CH1 just for reference
//const int temp2Pin = 2; // ADC1_CH2 just for reference
//const int ubatPin = 3; // ADC1_CH3 just for reference
const int unused1Pin = 4;
const int unused2Pin = 5;
const int shdnopPin = 6; // enable OP for PT100 1 and 2
const int shdnldoPin = 7; // enable 1.8V LDO
const int ledPin = 8;   // blue user led
const int buttonbootPin = 9;  // boot button / user button
const int chargingPin = 10;   // lo while charging
// const int i2c_scl = 20;
// const int i2c_sda = 21;

uint8_t btn_flag = 0;

// interrupt
void IRAM_ATTR rstbtn_isr(){
  btn_flag = 1;
}

void setup_pins(){
  // pins
  pinMode(readyPin, INPUT);
  pinMode(unused1Pin, OUTPUT);
  pinMode(unused2Pin, OUTPUT);
  pinMode(shdnopPin, OUTPUT);
  pinMode(shdnldoPin, OUTPUT);
  pinMode(ledPin, OUTPUT);
  pinMode(buttonbootPin, INPUT_PULLUP);
  pinMode(chargingPin, INPUT);

  digitalWrite(unused1Pin, 0);
  digitalWrite(unused2Pin, 0);
  digitalWrite(shdnopPin, 0);
  digitalWrite(shdnldoPin, 0);
  digitalWrite(ledPin, 0);
  // interrupt
  attachInterrupt(digitalPinToInterrupt(buttonbootPin), rstbtn_isr, FALLING);
}

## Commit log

2025-10-04 Createt reop and copy existing data
    [ESP32-C3_Dev.kicad_pcb, ESP32-C3_Dev.kicad_sch]
2025-10-05 wip schematic
    [ESP32-C3_Dev.kicad_pcb, ESP32-C3_Dev.kicad_sch, controller.kicad_sch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]
2025-10-10 wip - schematic and layout
    [ESP32-C3_Dev.kicad_pcb, controller.kicad_sch, powersupply.kicad_sch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]
2025-10-15 wip
    lcsc part numbers
    [ESP32-C3_Dev.kicad_pcb, ESP32-C3_Dev.kicad_sch, controller.kicad_sch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]
2025-10-16 level shift for op en added
    [ESP32-C3_Dev.kicad_pcb, ESP32-C3_Dev.kicad_sch, controller.kicad_sch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]
2025-10-25 wip
    changed folder structure
    [ESP32-C3_Dev.kicad_pcb, ESP32-C3_Dev.kicad_sch, ESP32-C3_Dev_BOM.csv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]
2025-10-25 wip
    added screenshots, modified battery connection and silkscreen
    [ESP32-C3_Dev.kicad_pcb, powersupply.kicad_sch]
2025-11-01 First Release
    HW ordered at Aisler, SW wip
    [ESP32-C3_Dev.kicad_pcb, bom.csv, designators.csv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]
2025-11-07 adding buck-boost
    [ESP32-C3_Dev.kicad_pcb, powersupply.kicad_sch]
2025-11-28 mqtt und oled implementiert wip
    [powersupply.kicad_sch]
2025-12-03 V2 fertig gestellt!
    [ESP32-C3_Dev.kicad_pcb, powersupply.kicad_sch, pt100.kicad_sch]
2026-01-09 housing created
    [ESP32-C3_Dev.kicad_pcb, Housing-Bottom.step, Housing-Top.step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]
2026-01-09 chaged readme
    [ESP32-C3_Dev.kicad_pcb, Housing.FCStd]
2026-01-20 wip
    custom design rule, optimized layout,
    [ESP32-C3_Dev.kicad_pcb, ESP32-C3_Dev.kicad_sch, controller.kicad_sch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]
2026-01-23 V2.1 finished and ordered
    [ESP32-C3_Dev.kicad_pcb]
2026-01-23 added stencil jig
    [ESP32-C3_Dev.kicad_pcb, Stencil Jig-BodyPad002.step, Stencil Jig.FCStd]
2026-02-18 added production files
    [bom.csv, bom.ods, designators.csv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]
2026-02-18 big cleanup, new structure
    added production and source folder for better structure
    [BMP388.step, C_0603_1608Metric.step, C_0805_2012Metric.step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]
2026-02-22 FW added storage manager
    writes after flashing default values to flash to prevent garbage
    [20260221_Stencil Jig-BodyPocket001.step, Stencil Jig.FCStd]

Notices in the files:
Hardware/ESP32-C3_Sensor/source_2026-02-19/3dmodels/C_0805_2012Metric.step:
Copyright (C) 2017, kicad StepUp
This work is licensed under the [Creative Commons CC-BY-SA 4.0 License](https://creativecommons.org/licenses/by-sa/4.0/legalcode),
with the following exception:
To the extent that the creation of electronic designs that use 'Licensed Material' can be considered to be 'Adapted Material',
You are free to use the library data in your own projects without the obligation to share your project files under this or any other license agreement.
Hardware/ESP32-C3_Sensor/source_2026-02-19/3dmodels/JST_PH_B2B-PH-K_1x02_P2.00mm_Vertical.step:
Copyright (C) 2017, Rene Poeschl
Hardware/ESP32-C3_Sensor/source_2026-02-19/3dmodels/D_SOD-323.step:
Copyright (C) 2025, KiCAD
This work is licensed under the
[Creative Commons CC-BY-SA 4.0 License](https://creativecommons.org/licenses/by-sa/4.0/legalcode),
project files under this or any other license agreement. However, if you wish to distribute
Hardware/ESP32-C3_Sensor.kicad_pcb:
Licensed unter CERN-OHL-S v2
